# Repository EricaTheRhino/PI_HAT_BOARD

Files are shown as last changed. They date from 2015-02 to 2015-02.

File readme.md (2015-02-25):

# Erica HAT
A raspberry pi HAT containing the interfaces used on Erica.
This board has the hardware for all of Erica's functions, however only some will be populated on each pi

## Board modules

* **ID EEPROM** as per the hat specification.
* **Button and Status Indicator** to provide information on the state of the pi.
* **DC Input** allows powering of the pi through the HAT.
* **GPIO Breakout** an 8P8C connector containing broken out GPIO, used for the touch sensors.
* **Temperature Sensor** for measuring Erica's internal temperature.
* **Real Time Clock** maintains a time reference when Erica is powered off.
* **Webcam Led Controller** controls the brightness on the eye webcam LEDs also has USB passthough to the webcam.
* **Servo Connector** for connecting the eye servos (directly connected to gpio for use with servoblaster).
* **DMX Interface** for controlling DMX fixtures from the pi.
* **Debug USB-serial** connects to the pi's console for debugging.

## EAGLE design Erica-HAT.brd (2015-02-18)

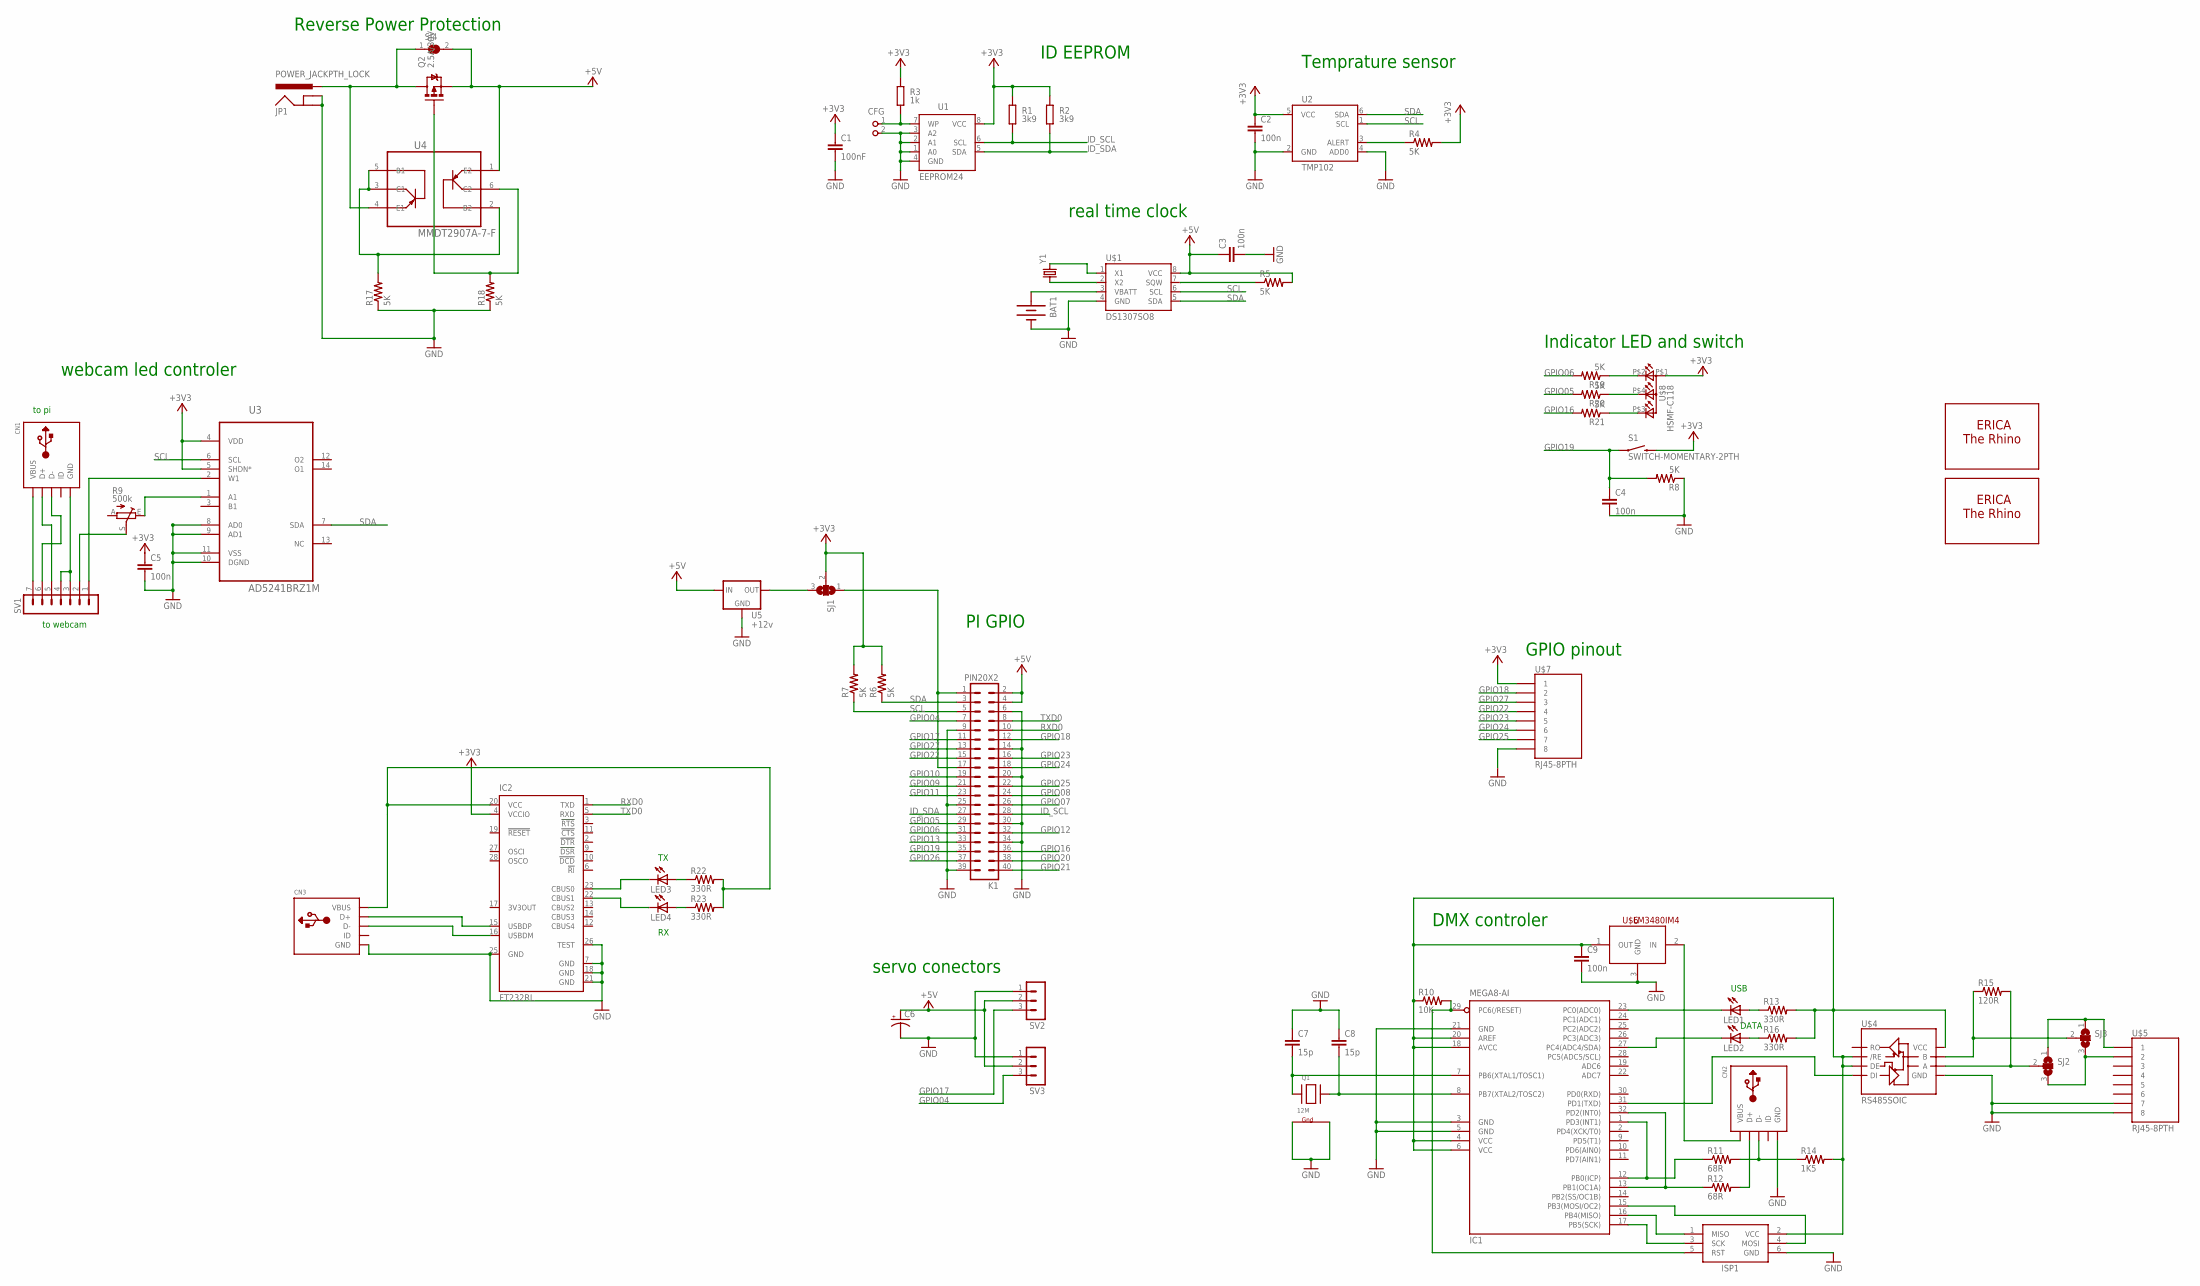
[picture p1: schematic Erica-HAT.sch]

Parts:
BAT1: BATTERY12MM; BATTCON_12MM
C1: 100nF; C0805K
C2, C3, C4, C5, C9: 100n; 0603-CAP
C6: CAP_POLPTH2; CPOL-RADIAL-10UF-25V
C7, C8: 15p; 0603-CAP
CFG: PIN2_100; PIN_W_2
CN1, CN2, CN3: USBMINIB; USB-MINIB
IC1: MEGA8-AI; TQFP32-08
IC2: FT232RL; SSOP28
ISP1: AVRISP-6; AVRISP
JP1: POWER_JACKPTH_LOCK; POWER_JACK_PTH_LOCK
K1: PIN20X2; PIN_20X2
LED1, LED2, LED3, LED4: LEDCHIP-LED0603; CHIP-LED0603
Q1: 12M; NX3225
Q2: 2.5A/30V; SOT23-3
R1, R2: 3k9; M0805; TOLERANCE 5%
R3: 1k; M0805; TOLERANCE 5%
R4, R5, R6, R7, R8, R17, R18, R19, R20, R21: 5K; 0603-RES
R9: 500k; B25U
R10: 10K; 0603-RES
R11, R12: 68R; 0603-RES
R13, R16, R22, R23: 330R; 0603-RES
R14: 1K5; 0603-RES
R15: 120R; 0603-RES
S1: SWITCH-MOMENTARY-2PTH; TACTILE-PTH
SJ1, SJ2, SJ3: SJ2W; SJ_2
SJ4: SJ
SV1: MA07-1
SV2, SV3: MA03-1
U1: EEPROM24; SOIC8
U2: TMP102; SOT563
U3: AD5241BRZ1M; SOIC127P600X175-14N
U4: MMDT2907A-7-F; SOT65P210X110-6N
U5: +12v; SOT223
U$1: DS1307SO8; SO08
U$2: ERICALOGO; ERICA_LOGO
U$3: ERICASILHOUETTE; ERICA_SILHOUETTE
U$4: RS485SOIC; SO08
U$5, U$7: RJ45-8PTH; RJ45-8
U$6: LM3480IM4; SOT23-3
U$8: HSMF-C118
Y1: CRYSTAL32-SMD; CRYSTAL-32KHZ-SMD

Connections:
+3V3: C1.1, C2.1, C5.1, IC2.4 (VCCIO), R1.2, R2.2, R3.2, R4.2, R6.2, R7.2, S1.3 (2), SJ1.2, U1.8 (VCC), U2.5 (VCC), U3.4 (VDD), U3.5 (SHDN*), U$7.1, U$8.P$1 (A2)
+5V: C3.1, C6.1 (+), K1.2, K1.4, Q2.2 (S), R5.2, SJ4.2, SV2.2, SV3.2, U4.1 (E2), U5.1 (IN), U$1.8 (VCC)
GND: BAT1.GND (-), C1.2, C2.2, C3.2, C4.2, C5.2, C6.2 (-), C7.1, C8.1, C9.2, CFG.2, CN2.GND, CN3.GND, IC1.3 (GND), IC1.5 (GND), IC1.21 (GND), IC2.7 (GND), IC2.18 (GND), IC2.21 (GND), IC2.25 (GND), IC2.26 (TEST), ISP1.6 (GND), JP1.GND, JP1.GNDBREAK, K1.6, K1.9, K1.14, K1.20, K1.25, K1.30, K1.34, K1.39, Q1.2 (G1), Q1.4 (G2), R8.1, R17.1, R18.1, SV2.1, SV3.1, U1.1 (A0), U1.2 (A1), U1.3 (A2), U1.4 (GND), U2.2 (GND), U2.4 (ADD0), U3.8 (AD0), U3.9 (AD1), U3.10 (DGND), U3.11 (VSS), U5.2 (GND), U$1.4 (GND), U$4.5 (GND), U$5.7, U$5.8, U$6.3 (GND), U$7.8
GPIO04: K1.7, SV3.3
GPIO05: K1.29, R20.2
GPIO06: K1.31, R19.2
GPIO07: K1.26
GPIO08: K1.24
GPIO09: K1.21
GPIO10: K1.19
GPIO11: K1.23
GPIO12: K1.32
GPIO13: K1.33
GPIO16: K1.36, R21.2
GPIO17: K1.11, SV2.3
GPIO18: K1.12, U$7.2
GPIO19: C4.1, K1.35, R8.2, S1.1
GPIO20: K1.38
GPIO21: K1.40
GPIO22: K1.15, U$7.4
GPIO23: K1.16, U$7.5
GPIO24: K1.18, U$7.6
GPIO25: K1.22, U$7.7
GPIO26: K1.37
GPIO27: K1.13, U$7.3
ID_SCL: K1.28, R1.1, U1.6 (SCL)
ID_SDA: K1.27, R2.1, U1.5 (SDA)
unnamed: R4.1, U2.3 (ALERT)
unnamed: BAT1.PWR@1 (+), U$1.3 (VBATT)
unnamed: CFG.1, R3.1, U1.7 (WP)
unnamed: R5.1, U$1.7 (SQW)
unnamed: R9.E, U3.1 (A1)
unnamed: R19.1, U$8.P$2 (CRED)
unnamed: U$1.1 (X1), Y1.X2 (2)
unnamed: U$1.2 (X2), Y1.X1 (1)
unnamed: R20.1, U$8.P$4 (CBLUE)
unnamed: R21.1, U$8.P$3 (CGREEN)
unnamed: SJ1.3, U5.3 (OUT)
unnamed: SJ2.1, SJ3.1, U$5.1
unnamed: CN1.GND, SV1.3, SV1.4
unnamed: CN1.D+, SV1.5
unnamed: CN1.D-, SV1.6
unnamed: CN1.VBUS, SV1.7
unnamed: SV1.1, U3.2 (W1)
unnamed: SJ2.3, SJ3.3, U$5.2
unnamed: R9.S, SV1.2
unnamed: C7.2, IC1.7 (PB6(XTAL1/TOSC1)), Q1.1 (X1)
unnamed: C8.2, IC1.8 (PB7(XTAL2/TOSC2)), Q1.3 (X2)
unnamed: IC1.29 (PC6(/RESET)), ISP1.5 (RST), R10.2
unnamed: IC1.13 (PB1(OC1A)), IC1.32 (PD2(INT0)), R12.1
unnamed: IC1.1 (PD3(INT1)), IC1.12 (PB0(ICP)), R11.1
unnamed: CN2.D-, R11.2, R14.1
unnamed: CN2.D+, R12.2
unnamed: IC1.23 (PC0(ADC0)), LED1.C
unnamed: LED1.A, R13.1
unnamed: IC1.31 (PD1(TXD)), U$4.4 (DI)
unnamed: C9.1, IC1.4 (VCC), IC1.6 (VCC), IC1.18 (AVCC), IC1.20 (AREF), ISP1.2 (VCC), R10.1, R13.2, R14.2, R16.2, U$4.2 (/RE), U$4.3 (DE), U$4.8 (VCC), U$6.1 (OUT)
unnamed: R15.1, SJ3.2, U$4.7 (B)
unnamed: R15.2, SJ2.2, U$4.6 (A)
unnamed: CN2.VBUS, U$6.2 (IN)
unnamed: IC1.16 (PB4(MISO)), ISP1.1 (MISO)
unnamed: IC1.17 (PB5(SCK)), ISP1.3 (SCK)
unnamed: IC1.15 (PB3(MOSI/OC2)), ISP1.4 (MOSI)
unnamed: IC1.27 (PC4(ADC4/SDA)), LED2.C
unnamed: JP1.PWR, Q2.3 (D), SJ4.1, U4.4 (E1)
unnamed: LED2.A, R16.1
unnamed: R17.2, U4.2 (B2), U4.3 (C1), U4.5 (B1)
unnamed: Q2.1 (G), R18.2, U4.6 (C2)
unnamed: LED3.A, R22.1
unnamed: CN3.D-, IC2.16 (USBDM)
unnamed: K1.1, K1.17, SJ1.1
unnamed: CN3.D+, IC2.15 (USBDP)
unnamed: LED4.A, R23.1
unnamed: IC2.23 (CBUS0), LED3.C
unnamed: IC2.22 (CBUS1), LED4.C
unnamed: CN3.VBUS, IC2.20 (VCC), R22.2, R23.2
RXD0: IC2.1 (TXD), K1.10
SCL: K1.5, R7.1, U2.1 (SCL), U3.6 (SCL), U$1.6 (SCL)
SDA: K1.3, R6.1, U2.6 (SDA), U3.7 (SDA), U$1.5 (SDA)
TXD0: IC2.5 (RXD), K1.8

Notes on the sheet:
ID EEPROM
PI GPIO
Temprature sensor
real time clock
Indicator LED and switch
to pi
to webcam
webcam led controler
servo conectors
DMX controler
GPIO pinout
Reverse Power Protection
USB
DATA

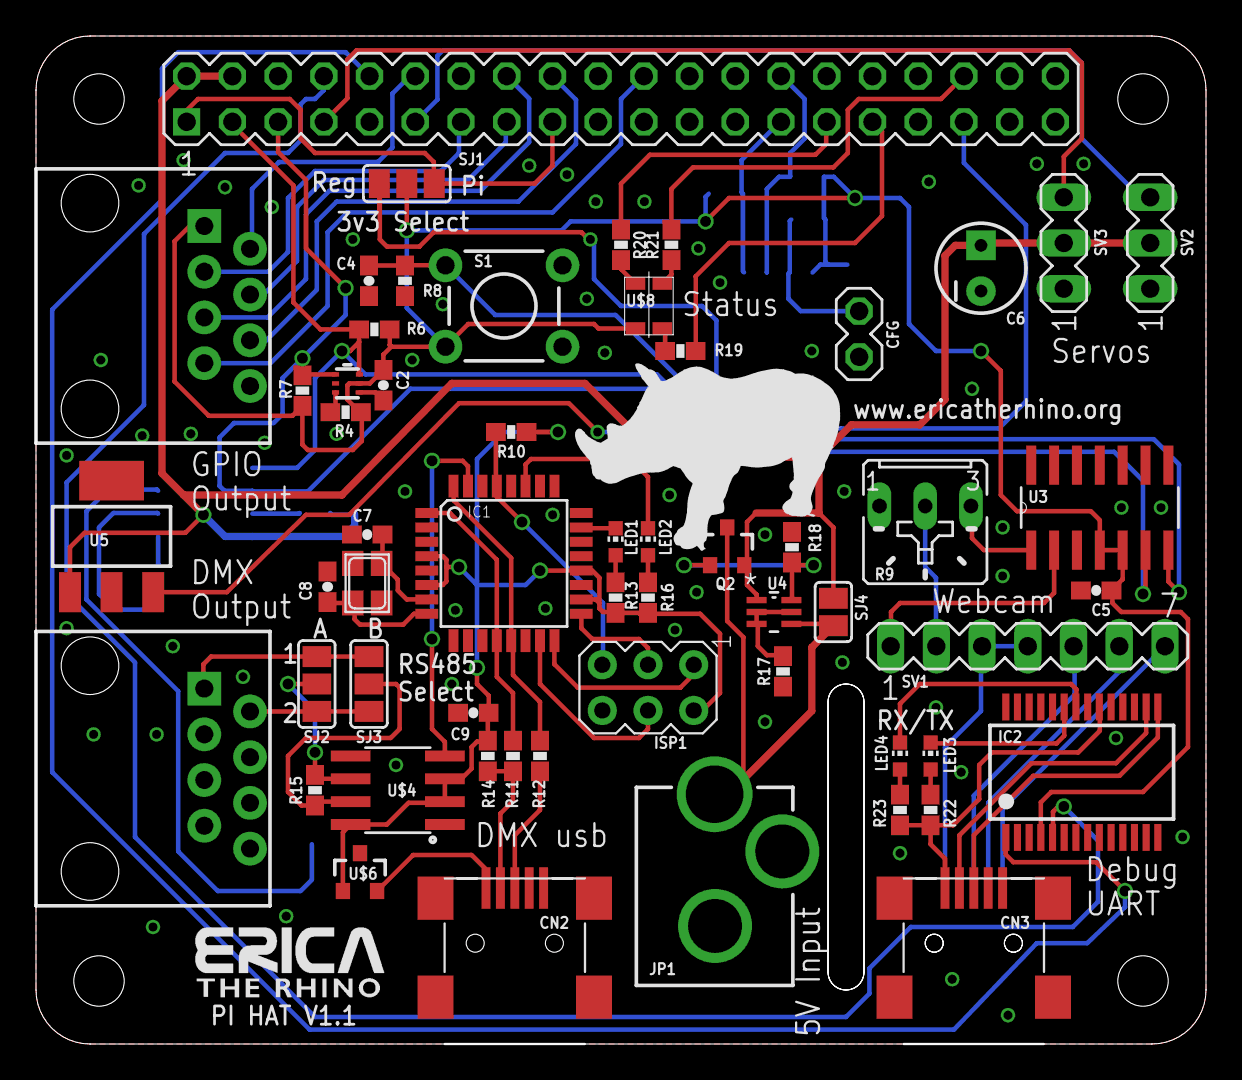
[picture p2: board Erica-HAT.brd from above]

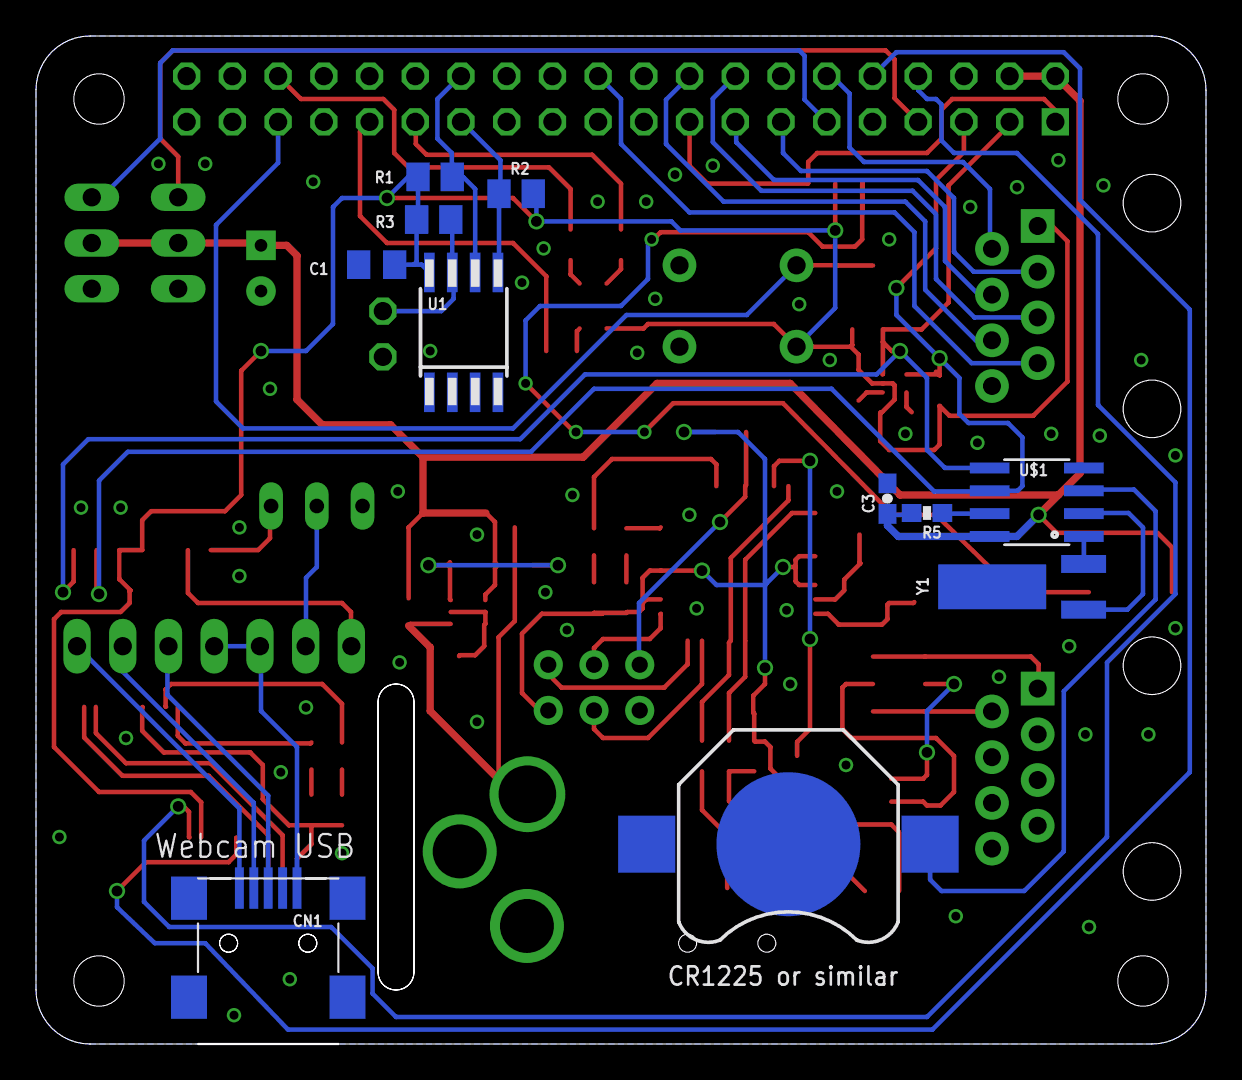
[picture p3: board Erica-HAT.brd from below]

Board: 2 copper layers, 65.0 x 56.0 mm, 70 parts (11 on the bottom side), 70 nets.

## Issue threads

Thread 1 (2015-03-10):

Q1 has wrong footprint

Tyler-Ward, 2015-03-10:
Q1 has the pads in the wrong position, this can be solved by soldering the crystal at 90 degrees from the position marked on the silkscreen.

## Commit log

2015-02-16 Initial HAT PCB design
    [Erica-HAT.brd, Erica-HAT.sch]
2015-02-16 Fixed remaining air wires. Added additional stitching. DRC clean.
    [Erica-HAT.brd]
2015-02-16 Added USB to serial for debug
    [Erica-HAT.brd, Erica-HAT.sch]
2015-02-17 Added silkscreen labels
    [Erica-HAT.brd, Erica-HAT.sch]
2015-02-17 Added more stitching vias. Hackvana DRC rules pass.
    [Erica-HAT.brd]
2015-02-18 changes for cam output
    [Erica-HAT.brd]
2015-02-18 Fixed URL and some other silkscreen issues
    [Erica-HAT.brd]

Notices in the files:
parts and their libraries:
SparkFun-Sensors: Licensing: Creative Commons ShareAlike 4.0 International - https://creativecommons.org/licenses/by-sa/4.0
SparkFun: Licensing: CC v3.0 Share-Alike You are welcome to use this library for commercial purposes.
